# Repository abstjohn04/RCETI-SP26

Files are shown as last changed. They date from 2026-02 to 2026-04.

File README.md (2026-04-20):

# RCETI

Robotic Control of Endotracheal Tube Insertion

## Overview

R.C.E.T.I is a ROS 2 autonomous intubation device. The system utilizes a multi axis rigid linear actuator frame to position the device at the patient's airway, and a 4 tendon continuum robotic tube to safely navigate the throat.

This project assumes the user is controlling the robot remotely via a Raspberry Pi and is using Ubuntu 22.04 LTS.

### Github Branches

**RCETI is currently divided into two branches.**  

The "main" branch contains the most recent stable code that has been tested on the physical robot. It contains updated and more precise servo movements. It does not contain the machine learning algorithms or the updated simulation environment.  

The "development" branch contains the latest code. It has not been tested on the physical robot. It contains the machine learning node and a more polished simulation environment and math engine.

### Requirements

* Ubuntu 22.04
* ROS 2
* Raspberry Pi

### File Structure

#### The workspace is divided into specific ROS 2 packages handling different levels of the robotic stack

**rceti_support**: Contains the URDF, Xarco, and 3D STIL meshes defining the rigid physical frame of the robot.

**rceti_continuum**: The core mathematical engine. It calculates the inverse kinematics (tendon lengths).

**rceti_controller**: The hardware interface running on the Raspberry Pi.

**rceti_keyboard**: A node allowing for manual control of the four independend continuum tendons via keyboard inputs

**rceti_deployment**: The launch files that tie the simulation, hardware, and math nodes together. Contains robot parameters in config/robot_params.yaml

**rceti_vision**: The input node for the machine learning algorithms.

## Installation

See [INSTALL.md](docs/INSTALL.md) to install ROS 2 and setup the environment on the Ubuntu host machine.

## Network Setup

See [NETWORK.md](docs/NETWORK.md) to access the Raspberry Pi.

## Usage

Before launching any ROS node, the user must first source the environment and build.

`colcon build --cmake-args -DCMAKE_EXPORT_COMPILE_COMMANDS=ON`

`source install/setup.bash`

Afterwards, the full network can be launched.

### Commands

`colcon build --packages-select package_name` - Builds a specific node

`ros2 launch rceti_deployment rceti_deployment.launch.xml` - Runs the whole robot system with machine learning disabled. Manual keyboard controls enabled.

`ros2 launch rceti_deployment rceti_deployment.launch.xml use_ai:=true` - Runs the whole robot system with machine learning enabled. Launches mock camera and vision bridge. Manual keyboard controls disabled. UNAVAILABLE IF USING MAIN BRANCH.

`ros2 launch package_name package_launch_file` - Launches a package's launch file (see names of launch files in codebase).

`ros2 run package_name package_run_file` - Runs a specific eligible file in a node (see names of files in codebase).

### RViz simulation tool

This tool launches with the rceti_continuum node. It fetches the modeled meshes from rceti_support and simulates them according to the urdf files (See invididual nodes' .urdf and .xacro files for more details on what is launched and created).  

To disable the Transform frames (all the green, red and blue lines) in the simulation, uncheck the "TF" button in the left settings screen.

### Moving the robot

If you are using the machine learning node with the mock camera, it will automatically move for you!  

To manually move the robot, the rceti_keyboard node must be launched. This will launch a separate terminal which outputs coordinates.  

To adjust the position of the servo mount, use A and D to move left and right, and W and S to move up and down.  
Use L and P to adjust the angle of the servo mount.

To move the tube, use the left and right arrow keys to adjust the Y coordinate (pitch) and the up and down arrow keys to adjust the X coordinate (yaw).

## License & Acknowledgements

This project is licensed under the Apache License 2.0.

Original Work: This repository is a derivative work based on the original [RCETI robotics project](https://github.com/bturner86239/RCETI/graphs/contributors). For a list of original authors, please visit the contributors page of the original repository at `https://github.com/bturner86239/RCETI/graphs/contributors`.

Modifications: In 2026, CSE 2.3 modified the source code, hardware architecture, and simulation environment to implement an independent 4-servo perpendicular continuum drive.

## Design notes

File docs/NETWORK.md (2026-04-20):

# RCETI Network Setup

## Setting Up Static IP on Ubuntu Host

1. Open Settings > Network.
2. Click on Wired Connection (the Ethernet interface).
3. Click Settings (⚙️).
4. Go to the IPv4 tab.
5. Select Manual and set:

    * Address: 192.168.2.1
    * Netmask: 255.255.255.0
    * Gateway: Leave blank

6. Click Apply and disconnect/reconnect Ethernet.

## Setting Up ROS to use static IP

Run these commands in your Ubuntu 22.04 terminal to bind ROS 2 traffic to the Ethernet interface. This will allow communication with the Raspberry Pi.

`echo "export ROS_DOMAIN_ID=7" >> ~/.bashrc ` \
`echo "export ROS_IP=$(hostname -I | awk '{print $1}')" >> ~/.bashrc` \
`echo "export ROS_HOSTNAME=$(hostname -I | awk '{print $1}')" >> ~/.bashrc` \
`source ~/.bashrc` \

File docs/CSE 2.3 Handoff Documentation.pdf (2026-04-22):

# Overview

## https://github.com/abstjohn04/RCETI-SP26

This handoff packet details what team CSE 2.3 completed, the next steps that should be taken, and how to install and use the system.

# What was completed

## Implemented 4 servo design

CSE 2.3 successfully updated the system to support the new 4 servo design. Specifically, it added new variables to the math engine to allow for full movement in the x direction (yaw) and y direction (pitch), added the new 4 servo mount to the simulation’s meshes, and updated the hardware controller to access the new servos.

## Enhanced servo movement

After adding support for the new servos, CSE 2.3 refined their operation. The math calculations were refined to have a smaller step size (allowing for more precise movements). Boundaries were added to the movements in the controller and simulation. Additionally, the code was simplified to allow for simpler modification of servo mappings.

Current math equations used in simulation:

The total bend angle (absolute angle between bottom base and tip):

θ = motor1

2
+ motor3

2

The bending plane angle (direction of the bend)
ϕ = arctan(motor1 / motor3)

The Curvature (tightness of curve dependent on length of the segment) κ = θ / L

## Created Machine Learning ROS Node

The machine learning algorithm was successfully integrated with the rest of the ROS ecosystem by creating a new ROS package (node) specifically to communicate with the separate machine learning codebase. This node uses a mock camera system to play the intubation video from the ML codebase. It contains the “best” (best.py) algorithm which analyzes the camera feed and broadcast movement commands to the math engine and then to the simulation and controller.

## Cleaned up existing codebase

CSE 2.3 removed old files left from previous teams, removed duplicated codefiles, and added detailed documentation to new code in the form of Doxygen comments.

# Future Work Recommendations

## Increased testing with physical robot

CSE 2.3 was not able to thoroughly test the controller node with the physical robot due to hardware wiring issues. While simulation testing proved successful, future teams must retest all of CSE 2.3’s new features on the physical hardware to ensure validity.

Additionally, the current machine learning node uses a mock camera. It is not integrated with the physical camera. To allow the machine learning algorithm to work as intended, any hardware issues with the robot must be corrected and then the camera feed must be fed into the ROS machine learning node. A mock mouth and throat must also be used to allow the machine learning algorithms to work.

## Refine mathematics and bending step size

The current mathematics for the simulation, controller and machine learning must be updated to reflect the dimensions of the actual endotracheal tube to be used. The number of segments and disks and their sizes must be updated in the robot_params.yaml file to allow for accurate calculations. Other mathematical formulas, such as inverse kinematics, should be explored.

## Integrate manual override of machine learning node

Currently, the keyboard node and the ML node cannot be launched simultaneously, due to a joint publishing conflict. To allow for the ability to stop the ML node and give control back to the keyboard, this conflict must be resolved.

## Unified GUI

The current implementation relies on entering terminal commands and interacting through separate gnome terminals. This is unappealing and disconnected. A GUI should be created to allow for easy navigation of the robot, allow for manual keyboard override, and display detailed information about the status of the robot, camera, and ROS system.

# README.md

## https://github.com/abstjohn04/RCETI-SP26/blob/main/README.md

RCETI
Robotic Control of Endotracheal Tube Insertion

Overview
R.C.E.T.I is a ROS 2 autonomous intubation device. The system utilizes a multi axis rigid linear actuator frame to position the device at the patient's airway, and a 4 tendon continuum robotic tube to safely navigate the throat.

This project assumes the user is controlling the robot remotely via a Raspberry Pi and is using Ubuntu 22.04 LTS.

Github Branches
RCETI is currently divided into two branches.

The "main" branch contains the most recent stable code that has been tested on the physical robot. It contains updated and more precise servo movements. It does not contain the machine learning algorithms or the updated simulation environment.

The "development" branch contains the latest code. It has not been tested on the physical robot. It contains the machine learning node and a more polished simulation environment and math engine.

Requirements
Ubuntu 22.04
ROS 2
Raspberry Pi
File Structure
The workspace is divided into specific ROS 2 packages handling different levels of the robotic stack
rceti_support: Contains the URDF, Xarco, and 3D STIL meshes defining the rigid physical frame of the robot.

rceti_continuum: The core mathematical engine. It calculates the inverse kinematics (tendon lengths).

rceti_controller: The hardware interface running on the Raspberry Pi.

rceti_keyboard: A node allowing for manual control of the four independent continuum tendons via keyboard inputs rceti_deployment: The launch files that tie the simulation, hardware, and math nodes together. Contains robot parameters in config/robot_params.yaml

rceti_vision: The input node for the machine learning algorithms.

Installation
See INSTALL.md to install ROS 2 and setup the environment on the Ubuntu host machine.

Network Setup
See NETWORK.md to access the Raspberry Pi.

Usage
Before launching any ROS node, the user must first source the environment and build.

colcon build --cmake-args -DCMAKE_EXPORT_COMPILE_COMMANDS=ON

source install/setup.bash

Afterwards, the full network can be launched.

Commands
colcon build --packages-select package_name - Builds a specific node

ros2 launch rceti_deployment rceti_deployment.launch.xml - Runs the whole robot system with machine learning disabled. Manual keyboard controls enabled.

ros2 launch rceti_deployment rceti_deployment.launch.xml use_ai:=true - Runs the whole robot system with machine learning enabled. Launches mock camera and vision bridge. Manual keyboard controls disabled. UNAVAILABLE IF USING MAIN BRANCH.

ros2 launch package_name package_launch_file - Launches a package's launch file (see names of launch files in codebase).

ros2 run package_name package_run_file - Runs a specific eligible file in a node (see names of files in codebase).

RViz simulation tool
This tool launches with the rceti_continuum node. It fetches the modeled meshes from rceti_support and simulates them according to the urdf files (See invididual nodes' .urdf and .xacro files for more details on what is launched and created).

To disable the Transform frames (all the green, red and blue lines) in the simulation, uncheck the "TF" button in the left settings screen.

Moving the robot
If you are using the machine learning node with the mock camera, it will automatically move for you!

To manually move the robot, the rceti_keyboard node must be launched. This will launch a separate terminal which outputs coordinates.

To adjust the position of the servo mount, use A and D to move left and right, and W and S to move up and down.
Use L and P to adjust the angle of the servo mount.

To move the tube, use the left and right arrow keys to adjust the Y coordinate (pitch) and the up and down arrow keys to adjust the X coordinate (yaw).

License & Acknowledgements
This project is licensed under the Apache License 2.0.

Original Work: This repository is a derivative work based on the original RCETI robotics project. For a list of original authors, please visit the contributors page of the original repository at https://github.com/bturner86239/RCETI/graphs/contributors.

Modifications: In 2026, CSE 2.3 modified the source code, hardware architecture, and simulation environment to implement an independent 4-servo perpendicular continuum drive.

# INSTALL.md

https://github.com/abstjohn04/RCETI-SP26/blob/main/docs/INSTALL.

## md (https://github.com/abstjohn04/RCETI-SP26/blob/main/docs/INSTALL.md)

RCETI System Setup & Installation
Setup Ubuntu Host System
First, we need to ensure the Ubuntu host machine is up to date and has the basic tools required to download the robotics software.

Open a new Terminal window (Ctrl + Alt + T).
Enter the following command and press enter:
sudo apt update && sudo apt upgrade -y
(Note: If prompted with "A new version of Ubuntu is available. Would you like to upgrade?", select "Do Not Upgrade". The robot specifically requires Ubuntu 22.04)
Restart the Ubuntu host machine
Install ROS 2
RCETI runs on ROS 2 Humble. Run the following commands one by one in your terminal to install the core robotic libraies.

Add the ROS 2 Repository
sudo apt install software-properties-common
sudo add-apt-repository universe
sudo apt update && sudo apt install curl -y
export ROS_APT_SOURCE_VERSION=$(curl -s
https://api.github.com/repos/ros-infrastructure/ros-apt-source/releases/latest | grep -F
"tag_name" | awk -F\" '{print $4}')
Install the Core Software
curl -L -o /tmp/ros2-apt-source.deb "https://github.com/ros-infrastructure/ros-apt-source/releases/download/${ROS_APT_SOURCE_VERSION}/ros2-apt-source_${ROS_APT_SOURCE_VERSION}.$(. /etc/os-release && echo ${UBUNTU_CODENAME:-${VERSION_CODENAME}})_all.deb"
sudo dpkg -i /tmp/ros2-apt-source.deb
sudo apt update && sudo apt install ros-humble-desktop -y && sudo apt install ros-humble-moveit -y && sudo apt install python3-colcon-common-extensions -y && sudo apt install python3-rosdep2 -y
Restart the Ubuntu host machine.
Set up the ROS environment
Next we will setup the ROS environment. Enter the following commands in your terminal one by one.

Source the setup files:
source /opt/ros/humble/setup.bash

If sourcing the files works, make it run automatically
echo "source /opt/ros/humble/setup.bash" >> ~/.bashrc
Close the current terminal and open a new one (Ctrl + Alt + T)
Create a new folder named “rceti_ws” with a subfolder named “src” in your home directory to store the code:
cd && mkdir -p rceti_ws/src
Download & Build the RCETI Code
Now that the robotics software is installed, we will download the RCETI code and the Machine Learning code. Once again, follow the steps and enter the commands in your terminal.

Install git:
sudo apt update && sudo apt install git -y
Clone the RCETI repo to rceti/src (make sure to include the dot at the end of the command!): cd ~/rceti/src && git clone https://github.com/abstjohn04/RCETI-SP26 .
Clone the Machine Learning repo to a new folder called ML (or any folder you wish): cd && mkdir ML && && cd ML && git clone https://github.com/github4bme/EndotrachealTubeModel . (Note: The machine learning repo is massive. It may take up to a hour to fully download.)
If you wish to use the mock machine learning camera, you must change the file path for "video_path" in rceti/src/rceti_vision/rceti_vision/mock_camera.py to match the location of your cloned machine learning repo.
Enter the rceti_ws/ directory and install dependencies:
cd ~/rceti_ws
rosdep update
rosdep install -i --from-path src --rosdistro humble -y colcon build
Restart the Ubuntu host machine (CRUCIAL!)
Validating the installation
To test the RCETI robot, enter the following command:
cd ~/rceti_ws/ && source install/setup.bash && ros2 launch rceti_deployment rceti_deployment.launch.xml

If the installation and launch was successful, three things will open on your screen:

The 3D Simulation (RViz): The 3D live model of the robot.
The Data Terminal: A window displaying the real time math calculations and the coordinates. The System Log: The original terminal where you typed the command will begin streaming the system health status.
To close the application, navigate to the System Log terminal window and press "Ctrcl + C". Close the other windows manually if needed.

See NETWORK.md for instructions on how to access the Raspberry Pi.

See the "Usage" section in README.md on how to use the system.

# NETWORK.md

## https://github.com/abstjohn04/RCETI-SP26/blob/main/docs/NETWOR K.md (https://github.com/abstjohn04/RCETI-SP26/blob/main/docs/NETWORK.md)

RCETI Network Setup
Setting Up Static IP on Ubuntu Host
Open Settings > Network.

Click on Wired Connection (the Ethernet interface).

Click Settings (⚙️).

Go to the IPv4 tab.

Select Manual and set:

Address: 192.168.2.1
Netmask: 255.255.255.0
Gateway: Leave blank
Click Apply and disconnect/reconnect Ethernet.

Setting Up ROS to use static IP
Run these commands in your Ubuntu 22.04 terminal to bind ROS 2 traffic to the Ethernet interface. This will allow communication with the Raspberry Pi.

echo "export ROS_DOMAIN_ID=7" >> ~/.bashrc
echo "export ROS_IP=$(hostname -I | awk '{print $1}')" >> ~/.bashrc
echo "export ROS_HOSTNAME=$(hostname -I | awk '{print $1}')" >> ~/.bashrc
source ~/.bashrc \

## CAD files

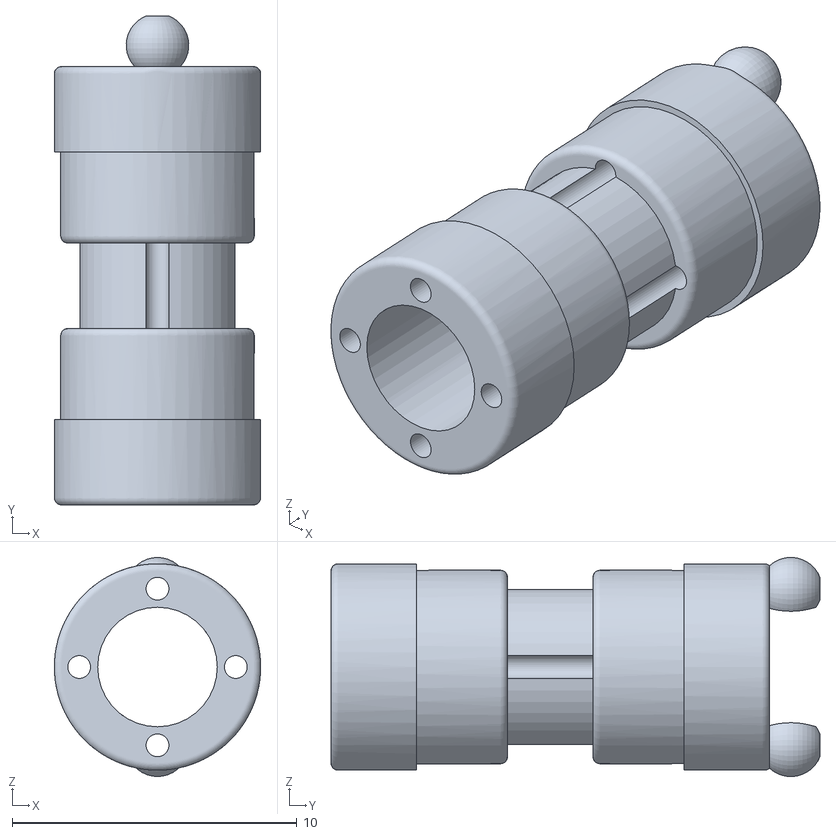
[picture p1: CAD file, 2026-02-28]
rceti_support/meshes/visual/scaled_down_by_1000/IF_camera_frame_V3.0_4.2mm_original.STL
7.25 x 17.2 x 7.70

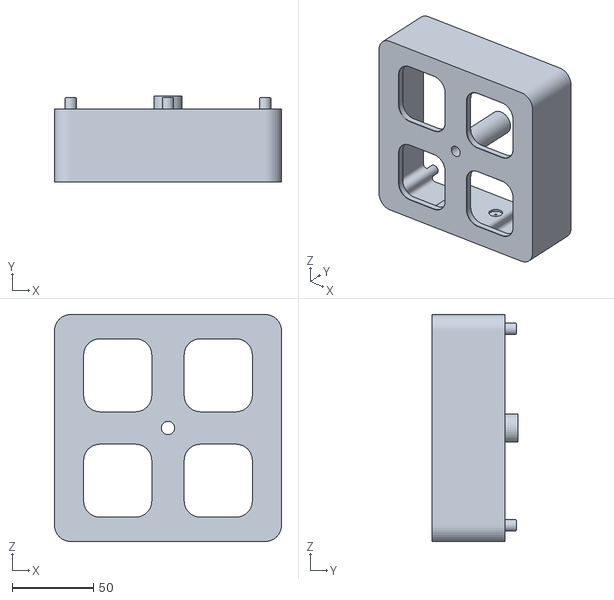
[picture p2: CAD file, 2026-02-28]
rceti_support/meshes/visual/scaled_down_by_1000/IF_Attachment_V9_Piece_bottom.STL
140.0 x 52.8 x 140.0

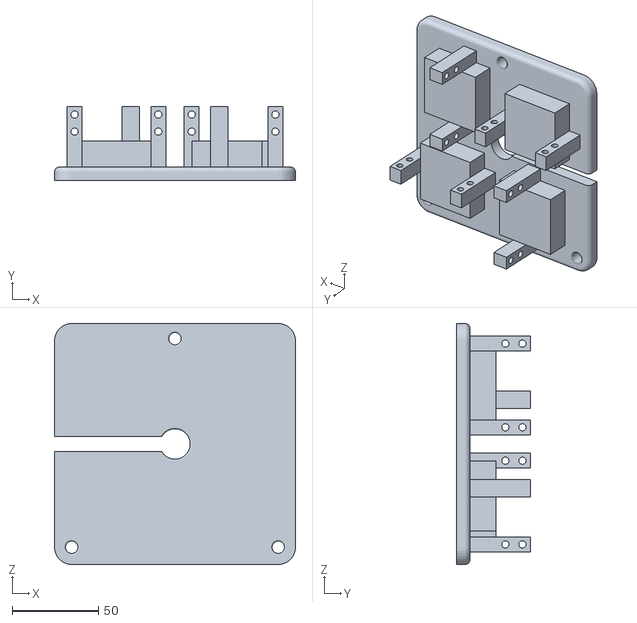
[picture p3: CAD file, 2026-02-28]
rceti_support/meshes/visual/scaled_down_by_1000/IF_Attachment_Piece_V1.4_Top.STL
140.0 x 42.8 x 140.0

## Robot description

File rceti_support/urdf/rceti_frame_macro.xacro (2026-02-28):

<?xml version="1.0" ?>
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
<robot xmlns:xacro="http://ros.org/wiki/xacro" name="rceti_robot">
    
    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
    
    <xacro:property name="meshes_directory" default=""/>

    <xacro:macro name="rceti_robot" params="meshes_directory">
        
        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
        <link name="base_link">
            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
        </link>

        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
        <link name="x_actuator_link">
            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
        </link>

        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
        <link name="x_slider_link">
            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
        </link>

        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
        <link name="z_actuator_link">
            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
        </link>

        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
        <link name="z_slider_link">
            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
            
        </link>

        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
        <link name="pitch_servo_link">
            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
        </link>

        <link name="pitch_servo_bottom_link">
            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
        </link>

        <link name="continuum_base_link">
            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
        </link>

        <link name="continuum_base_link_top">
            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
        </link>

        <link name="continuum_base_link_bottom">
            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
        </link>

        <link name="continuum_base_link_left">
            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
        </link>

        <link name="continuum_base_link_right">
            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
        </link>

        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
        <joint name="base_to_x_actuator" type="fixed">
            <parent link="base_link"/>
            <child link="x_actuator_link"/>
            <origin xyz="0 0 0.35"/>  
        </joint>

        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
        <joint name="x_actuator_to_x_slider" type="prismatic">
            <parent link="x_actuator_link"/>
            <child link="x_slider_link"/>
            <origin xyz="0.0580 0.027 0.014"/>
            <axis xyz="1 0 0"/>  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
            <limit effort="100.0" lower="0" upper="0.308" velocity="0.5"/>
        </joint>

        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
        <joint name="x_slider_to_z_actuator" type="fixed">
            <parent link="x_slider_link"/>
            <child link="z_actuator_link"/>
            <origin xyz="0 0.03965 0.13176"/>
        </joint>

        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
        <joint name="z_actuator_to_z_slider" type="prismatic">
            <parent link="z_actuator_link"/>
            <child link="z_slider_link"/>
            <origin xyz="0 0.026 -0.0580"/>
            <axis xyz="0 0 -1"/>
            <limit effort="100.0" lower="0.0" upper="0.309" velocity="0.5"/>
        </joint>

        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
        <joint name="z_slider_to_pitch_servo" type="revolute">
            <parent link="z_slider_link"/>
            <child link="pitch_servo_link"/>
            <origin xyz="0 0.02 0" rpy="${pi/2} 0 ${pi}"/>
            <axis xyz="0 0 1"/>
            <limit effort="50.0" lower="0.730" upper="-0.475" velocity="1.0"/>
        </joint>

        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
        <joint name="pitch_bottom_to_top" type="fixed">
            <parent link="pitch_servo_link"/>
            <child link="pitch_servo_bottom_link"/>
            <origin xyz="0 0.017 0"/>
        </joint>

        <joint name="continuum_top" type="revolute">
            <parent link="pitch_servo_bottom_link"/>
            <child link="continuum_base_link_top"/>
            <origin xyz="0 0.017 0"/>
            <axis xyz="0 0 1"/> 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
            <limit effort="50.0" lower="-0.5" upper="0.5" velocity="1.0"/> 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
        </joint>

        <joint name="continuum_bottom" type="revolute">
            <parent link="pitch_servo_bottom_link"/>
            <child link="continuum_base_link_bottom"/>
            <origin xyz="0 0.017 0"/>
            <axis xyz="0 0 1"/> 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
            <limit effort="50.0" lower="-0.5" upper="0.5" velocity="1.0"/> 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
        </joint>

        <joint name="continuum_left" type="revolute">
            <parent link="pitch_servo_bottom_link"/>
            <child link="continuum_base_link_left"/>
            <origin xyz="0 0.017 0"/>
            <axis xyz="0 0 1"/> 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
            <limit effort="50.0" lower="-0.5" upper="0.5" velocity="1.0"/> 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
        </joint>

        <joint name="continuum_right" type="revolute">
            <parent link="pitch_servo_bottom_link"/>
            <child link="continuum_base_link_right"/>
            <origin xyz="0 0.017 0"/>
            <axis xyz="0 0 1"/> 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
            <limit effort="50.0" lower="-0.5" upper="0.5" velocity="1.0"/> 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
        </joint>

    </xacro:macro>
    <xacro:rceti_robot meshes_directory="$(arg meshes_directory)"/>
</robot>

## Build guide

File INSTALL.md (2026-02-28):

# RCETI System Setup & Installation

## Setup Ubuntu Host System

First, we need to ensure the Ubuntu host machine is up to date and has the basic tools required to download the robotics software.

1. Open a new Terminal window (Ctrl + Alt + T).
2. Enter the following command and press enter:  
`sudo apt update && sudo apt upgrade -y`  
*(Note: If prompted with "A new version of Ubuntu is available. Would you like to upgrade?", select **"Do Not Upgrade"**. The robot specifically requires Ubuntu 22.04)*
3. Restart the Ubuntu host machine

## Install ROS 2

RCETI runs on ROS 2 Humble. Run the following commands one by one in your terminal to install the core robotic libraies.

1. Add the ROS 2 Repository
    * `sudo apt install software-properties-common`
    * `sudo add-apt-repository universe`
    * `sudo apt update && sudo apt install curl -y`
    * `export ROS_APT_SOURCE_VERSION=$(curl -s https://api.github.com/repos/ros-infrastructure/ros-apt-source/releases/latest | grep -F "tag_name" | awk -F\" '{print $4}')`
2. Install the Core Software
    * `curl -L -o /tmp/ros2-apt-source.deb "https://github.com/ros-infrastructure/ros-apt-source/releases/download/${ROS_APT_SOURCE_VERSION}/ros2-apt-source_${ROS_APT_SOURCE_VERSION}.$(. /etc/os-release && echo ${UBUNTU_CODENAME:-${VERSION_CODENAME}})_all.deb"`
    * `sudo dpkg -i /tmp/ros2-apt-source.deb`
    * `sudo apt update && sudo apt install ros-humble-desktop -y && sudo apt install ros-humble-moveit -y && sudo apt install python3-colcon-common-extensions -y && sudo apt install python3-rosdep2 -y`
3. Restart the Ubuntu host machine.

## Set up the ROS environment

Next we will setup the ROS environment. Enter the following commands in your terminal one by one.

1. Source the setup files:  
    `source /opt/ros/humble/setup.bash`
2. If sourcing the files works, make it run automatically  
    `echo "source /opt/ros/humble/setup.bash" >> ~/.bashrc`
3. Close the current terminal and open a new one (Ctrl + Alt + T)
4. Create a new folder named “rceti_ws” with a subfolder named “src” in your home directory to store the code:  
    ``cd && mkdir -p rceti_ws/src``

## Download & Build the RCETI Code

Now that the robotics software is installed, we will download the RCETI specific code. Once again, follow the steps and enter the commands in your terminal.

1. Install git:  
    `sudo apt update && sudo apt install git -y`
2. Clone the repo to rceti/src (make sure to include the dot at the end of the command!):  
    `cd ~/rceti/src && git clone https://github.com/abstjohn04/RCETI-SP26 .`
3. Enter the rceti_ws/ directory and install dependencies:  
    * `cd ~/rceti_ws`
    * `rosdep update`
    * `rosdep install -i --from-path src --rosdistro humble -y`
    * `colcon build`
4. Restart the Ubuntu host machine (CRUCIAL!)

## Running the Robot System

To Start the RCETI robot, enter the following command:  
    `cd ~/rceti_ws/ && source install/setup.bash && ros2 launch rceti_deployment rceti_deployment.launch.xml`

If the installation and launch was successful, four things will open on your screen:

1. **The 3D Simulation (RViz)**: The 3D live model of the robot.
2. **The Control Terminal**: A new terminal will pop up allowing you to use your WASD and Arrow keys to control the physical robot
3. **The Data Terminal**: A window displaying the real time math calculations and the coordinates.
4. **The System Log**: The original terminal where you typed the command will begin streaming the system health status.

To close the application, navigate to the System Log terminal window and press "Ctrcl + C". Close the other windows manually if needed

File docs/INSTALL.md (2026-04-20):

# RCETI System Setup & Installation

## Setup Ubuntu Host System

First, we need to ensure the Ubuntu host machine is up to date and has the basic tools required to download the robotics software.

1. Open a new Terminal window (Ctrl + Alt + T).
2. Enter the following command and press enter:  
`sudo apt update && sudo apt upgrade -y`  
*(Note: If prompted with "A new version of Ubuntu is available. Would you like to upgrade?", select **"Do Not Upgrade"**. The robot specifically requires Ubuntu 22.04)*
3. Restart the Ubuntu host machine

## Install ROS 2

RCETI runs on ROS 2 Humble. Run the following commands one by one in your terminal to install the core robotic libraies.

1. Add the ROS 2 Repository
    * `sudo apt install software-properties-common`
    * `sudo add-apt-repository universe`
    * `sudo apt update && sudo apt install curl -y`
    * `export ROS_APT_SOURCE_VERSION=$(curl -s https://api.github.com/repos/ros-infrastructure/ros-apt-source/releases/latest | grep -F "tag_name" | awk -F\" '{print $4}')`
2. Install the Core Software
    * `curl -L -o /tmp/ros2-apt-source.deb "https://github.com/ros-infrastructure/ros-apt-source/releases/download/${ROS_APT_SOURCE_VERSION}/ros2-apt-source_${ROS_APT_SOURCE_VERSION}.$(. /etc/os-release && echo ${UBUNTU_CODENAME:-${VERSION_CODENAME}})_all.deb"`
    * `sudo dpkg -i /tmp/ros2-apt-source.deb`
    * `sudo apt update && sudo apt install ros-humble-desktop -y && sudo apt install ros-humble-moveit -y && sudo apt install python3-colcon-common-extensions -y && sudo apt install python3-rosdep2 -y`
3. Restart the Ubuntu host machine.

## Set up the ROS environment

Next we will setup the ROS environment. Enter the following commands in your terminal one by one.

1. Source the setup files:  
    `source /opt/ros/humble/setup.bash`
2. If sourcing the files works, make it run automatically  
    `echo "source /opt/ros/humble/setup.bash" >> ~/.bashrc`
3. Close the current terminal and open a new one (Ctrl + Alt + T)
4. Create a new folder named “rceti_ws” with a subfolder named “src” in your home directory to store the code:  
    ``cd && mkdir -p rceti_ws/src``

## Download & Build the RCETI Code

Now that the robotics software is installed, we will download the RCETI code and the Machine Learning code. Once again, follow the steps and enter the commands in your terminal.

1. Install git:  
    `sudo apt update && sudo apt install git -y`
2. Clone the RCETI repo to rceti/src (make sure to include the dot at the end of the command!):  
    `cd ~/rceti/src && git clone https://github.com/abstjohn04/RCETI-SP26 .`
3. Clone the Machine Learning repo to a new folder called ML (or any folder you wish):
    `cd && mkdir ML && && cd ML && git clone https://github.com/github4bme/EndotrachealTubeModel .`
    *(Note: The machine learning repo is massive. It may take up to a hour to fully download.)*
4. If you wish to use the mock machine learning camera, you must change the file path for "video_path" in rceti/src/rceti_vision/rceti_vision/mock_camera.py to match the location of your cloned machine learning repo.
5. Enter the rceti_ws/ directory and install dependencies:  
    * `cd ~/rceti_ws`
    * `rosdep update`
    * `rosdep install -i --from-path src --rosdistro humble -y`
    * `colcon build`
6. Restart the Ubuntu host machine (CRUCIAL!)

## Validating the installation

To test the RCETI robot, enter the following command:  
    `cd ~/rceti_ws/ && source install/setup.bash && ros2 launch rceti_deployment rceti_deployment.launch.xml`

If the installation and launch was successful, three things will open on your screen:

1. **The 3D Simulation (RViz)**: The 3D live model of the robot.
2. **The Data Terminal**: A window displaying the real time math calculations and the coordinates.
3. **The System Log**: The original terminal where you typed the command will begin streaming the system health status.

To close the application, navigate to the System Log terminal window and press "Ctrcl + C". Close the other windows manually if needed.  

See [NETWORK.md](NETWORK.md) for instructions on how to access the Raspberry Pi.  

See the "Usage" section in [README.md](../README.md) on how to use the system.

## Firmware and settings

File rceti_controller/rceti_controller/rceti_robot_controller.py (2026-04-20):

# MODIFICATION NOTICE
# This file is part of a derivative work based on the original RCETI project (https://github.com/bturner86239/RCETI).
# It was modified by CSE 2.3 in March, 2026 in accordance with Section 4(b) of the Apache License 2.0.

# Major Changes:
# Added support for two new continuum_motors.
import math
import rclpy
from rclpy.node import Node
from sensor_msgs.msg import JointState
import time  # for delays/testing

# A try catch block to detect the raspberry pi. Enters mock mode for simulation testing if it is not detected.
try:
    import lgpio
    from adafruit_servokit import ServoKit
    import adafruit_motor.servo
    HARDWARE_MODE = True
    kit = ServoKit(channels=16)
    print("Raspberry Pi Hardware detected. Running in HARDWARE mode.")

except (ImportError, NotImplementedError):
    print("WARNING: Raspberry Pi Hardware not detected. Running in MOCK SIMULATION mode.")
    HARDWARE_MODE = False

    class MockServo:
        """A mock representation of an Adafruit servo motor for simulation testing."""
        
        def __init__(self):
            """Initializes the mock servo with a default actuation range."""
            self._angle = None
            self.actuation_range = 180
            
        def set_pulse_width_range(self, min_p, max_p):
            """Mocks the hardware method for setting the pulse width range.
            
            Args:
                min_p (int): The minimum pulse width in microseconds.
                max_p (int): The maximum pulse width in microseconds.
            """
            pass

        @property
        def angle(self):
            """Gets the current angle of the simulated servo.
            
            Returns:
                float: The current angle.
            """
            return self._angle
        
        @angle.setter
        def angle(self, val): 
            """Sets the angle of the simulated servo.
            
            Args:
                val (float): The desired angle to set.
            """
            self._angle = val

    class MockServoKit:
        """A mock representation of the Adafruit servo controller."""

        def __init__(self, channels):
            """Initializes the mock servo kit with a specified number of channels.
            
            Args:
                channels (int): The total number of servo channels available on the board.
            """
            self.servo = [MockServo() for _ in range(channels)]

    class MockLgpio:
        """A mock representation of the lgpio library for simulating Raspberry Pi GPIO pins."""

        def gpiochip_open(self, chip): 
            """Mocks opening the GPIO chip for access.
            
            Args:
                chip (int): The GPIO chip number to open.
                
            Returns:
                int: A dummy handle ID for the opened chip.
            """
            return 1
        
        def gpio_claim_output(self, chip, pin): 
            """Mocks claiming a specific GPIO pin for digital output.
            
            Args:
                chip (int): The handle ID of the GPIO chip.
                pin (int): The physical pin number to claim.
            """
            pass

        def gpio_write(self, chip, pin, val):
            """Mocks writing a digital high or low state to a GPIO pin.
            
            Args:
                chip (int): The handle ID of the GPIO chip.
                pin (int): The physical pin number to write to.
                val (int): The value to write (1 for HIGH, 0 for LOW).
            """
            pass

    kit = MockServoKit(channels=16)
    lgpio = MockLgpio()

TOPIC_SUBSCRIPTION_BUFFER = 5

class RCETIRobotController(Node):
    """RCETIRobotController is a ROS 2 node that controls the RCETI robot's stepper motors and pitch servo.

    Args:
        Node (Node): The node of the ROS 2 system that handles the robot's control logic.
    """

    def __init__(self):
        """Initializes the RCETIRobotController node, subscribes to the /joint_states topic, and sets up GPIO pins for stepper motors and servo motors."""
        
        super().__init__('rceti_controller')

        # Initialize servo motors
        self.servo1 = kit.servo[0]       # tilts continuum base
        self.servo2 = kit.servo[4]       # pulls continuum (N)
        self.servo3 = kit.servo[2]       # pulls continuum (S)
        self.servo4 = kit.servo[3]       # pulls continuum (W)
        self.servo5 = kit.servo[1]       # pulls continuum (E)

        self.servo1.actuation_range = 200
        self.servo1.set_pulse_width_range(500, 2000)

        # CONTINUUM SERVO BOUND CONSTANTS
        self.continuum_servo_half_range = 20
        self.continuum_servo_middle = 90

        # May need to adjust 
        self.servo2.actuation_range = 180
        self.servo2.set_pulse_width_range(500, 2500)
        # May need to adjust 
        self.servo3.actuation_range = 180
        self.servo3.set_pulse_width_range(500, 2500)
        # May need to adjust 
        self.servo4.actuation_range = 180
        self.servo4.set_pulse_width_range(500, 2500)
        # May need to adjust 
        self.servo5.actuation_range = 180
        self.servo5.set_pulse_width_range(500, 2500)

        # Subscribe to the /joint_states topic
        self.joint_state_sub = self.create_subscription(
            JointState,
            '/joint_states',
            self.joint_state_callback,
            TOPIC_SUBSCRIPTION_BUFFER
        )

        # Position tracking
        self.x_position = 0.0
        self.z_position = 0.0
        self.pitch_angle = 0.730

        # GPIO pin definitions
        self.X_DIRECTION_PIN = 21
        self.X_PULSE_PIN = 20
        self.Z_DIRECTION_PIN = 19
        self.Z_PULSE_PIN = 18

        # Open the GPIO chip and set the pins as output
        self.chip = lgpio.gpiochip_open(0)
        lgpio.gpio_claim_output(self.chip, self.X_DIRECTION_PIN)
        lgpio.gpio_claim_output(self.chip, self.X_PULSE_PIN)
        lgpio.gpio_claim_output(self.chip, self.Z_DIRECTION_PIN)
        lgpio.gpio_claim_output(self.chip, self.Z_PULSE_PIN)

        # Define stepper steps per unit in X and Z directions
        self.steps_per_mm_x = 40
        self.steps_per_mm_z = 40

    def joint_state_callback(self, msg):
        """Handles incoming joint state messages and moves the stepper motors accordingly.
        This function is called whenever a new message is received on the /joint_states topic.
        Moves the x stepper motor, z stepper motor, and pitch servo motor based on the joint states received.

        Args:
            msg (sensor_msgs/JointState.msg): The messages recieved from the /joint_states topic.
        """
        # Extract joint positions from the message
        try:
            x_index = msg.name.index('x_actuator_to_x_slider')
            z_index = msg.name.index('z_actuator_to_z_slider')
            pitch_index = msg.name.index('z_slider_to_pitch_servo')
            continuum_index_1 = msg.name.index('continuum_motor_1')
            continuum_index_2 = msg.name.index('continuum_motor_2')
            continuum_index_3 = msg.name.index('continuum_motor_3')
            continuum_index_4 = msg.name.index('continuum_motor_4')

            new_x_position = msg.position[x_index]
            new_z_position = msg.position[z_index]
            pitch_angle_msg = msg.position[pitch_index]
            continuum_angle_1 = msg.position[continuum_index_1]
            continuum_angle_2 = msg.position[continuum_index_2]
            continuum_angle_3 = msg.position[continuum_index_3]
            continuum_angle_4 = msg.position[continuum_index_4]

            # Handle X-axis movement
            if self.x_position != new_x_position:
                self.get_logger().info(f"Moving X to {new_x_position}")
                steps = int(abs(new_x_position - self.x_position) * 1000 * self.steps_per_mm_x)
                direction = 1 if new_x_position > self.x_position else 0
                self.move_stepper(steps, direction, self.X_DIRECTION_PIN, self.X_PULSE_PIN)
                self.x_position = new_x_position

            # Handle Z-axis movement
            if self.z_position != new_z_position:
                self.get_logger().info(f"Moving Z to {new_z_position}")
                steps = int(abs(new_z_position - self.z_position) * 1000 * self.steps_per_mm_z)
                direction = 1 if new_z_position > self.z_position else 0
                self.move_stepper(steps, direction, self.Z_DIRECTION_PIN, self.Z_PULSE_PIN)
                self.z_position = new_z_position

            # Handle pitch and continuum angles with safety clamps
            new_pitch_angle = self.clamp_angle(((pitch_angle_msg + 0.475) / 1.205) * 120)
            
            # new_continuum_1_pitch_angle = self.clamp_angle(((continuum_angle_1 + 0.475) / 1.205) * 120)
            # new_continuum_2_pitch_angle = self.clamp_angle(((continuum_angle_2 + 0.475) / 1.205) * 120)
            # new_continuum_3_pitch_angle = self.clamp_angle(((continuum_angle_3 + 0.475) / 1.205) * 120)
            # new_continuum_4_pitch_angle = self.clamp_angle(((continuum_angle_4 + 0.475) / 1.205) * 120)

            servo1_angle = self.clamp_continuum_angle(self.convert_continuum_angle(continuum_angle_1))
            servo2_angle = self.clamp_continuum_angle(self.convert_continuum_angle(continuum_angle_2))
            servo3_angle = self.clamp_continuum_angle(self.convert_continuum_angle(continuum_angle_3))
            servo4_angle = self.clamp_continuum_angle(self.convert_continuum_angle(continuum_angle_4))

            if (self.servo1.angle != new_pitch_angle): 
                self.get_logger().info(f"Adjusting pitch to {new_pitch_angle}")
                self.servo1.angle = new_pitch_angle

            if (self.servo2.angle != servo1_angle): 
                self.get_logger().info(f"Adjusting continuum 1 to {servo1_angle}")
                self.servo2.angle = servo1_angle

            if (self.servo3.angle != servo2_angle): 
                self.get_logger().info(f"Adjusting continuum 2 to {servo2_angle}")
                self.servo3.angle = servo2_angle
                
            if (self.servo4.angle != servo3_angle): 
                self.get_logger().info(f"Adjusting continuum 3 to {servo3_angle}")
                self.servo4.angle = servo3_angle

            if (self.servo5.angle != servo4_angle): 
                self.get_logger().info(f"Adjusting continuum 4 to {servo4_angle}")
                self.servo5.angle = servo4_angle

        except ValueError as e:
            self.get_logger().error(f"Joint name not found in joint_states: {e}")

    def move_stepper(self, steps, direction, direction_pin, pulse_pin, delay=0.001):
        """Stepper Motor Helper Function, handles all stepper movement

        Args:
            steps (int): the amount of "steps" the stepper motor will take
            direction (int/bool): the direction the stepper motor will move, 0 is for backward, 1 is for forward
            direction_pin (int): the GPIO pin used to set the direction of the stepper motor
            pulse_pin (int): the GPIO pin used to pulse the stepper motor
            delay (float, optional): the delay between steps, defaults to 0.001.
        """
        
        if HARDWARE_MODE:
            self.get_logger().info(f"Hardware pulsing: steps={steps}, dir={direction}")
            lgpio.gpio_write(self.chip, direction_pin, direction)

            for _ in range(steps):
                lgpio.gpio_write(self.chip, pulse_pin, 1)
                time.sleep(delay)
                lgpio.gpio_write(self.chip, pulse_pin, 0)
                time.sleep(delay)
        else:
            # Skip time.sleep() so it is reflected in simulation instanly
            self.get_logger().info(f"[MOCK] Simulated moving stepper: steps={steps}, dir={direction}")

    def clamp_angle(self, value):
        """Clamps the calculated angle between 0 and 120 degrees."""
        return max(0, min(120, int(value)))

    def convert_continuum_angle(self, value):
        """
        Converts value from joint state (-0.5, 0.5) to servo angle
        (continuum_servo_middle +- continuum_servo_half_angle).
        """
        return (value * self.continuum_servo_half_range * 2) + 90

    def clamp_continuum_angle(self, value):
        """Clamps the angle between the min and max range set by constants."""
        return max(
            self.continuum_servo_middle - self.continuum_servo_half_range,
            min(
                self.continuum_servo_middle + self.continuum_servo_half_range,
                value
            )
        )

def main(args=None):
    """The main function initializes the ROS 2 node and starts the RCETIRobotController.

    Args:
        args (N/A optional):Defaults to None, shouldn't be set to anything
    """
    rclpy.init(args=args)
    robot_controller = RCETIRobotController()
    rclpy.spin(robot_controller)

    robot_controller.destroy_node()
    rclpy.shutdown()

if __name__ == '__main__':
    main()

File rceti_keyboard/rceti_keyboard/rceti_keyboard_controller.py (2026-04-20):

# MODIFICATION NOTICE
# This file is part of a derivative work based on the original RCETI project (https://github.com/bturner86239/RCETI).
# It was modified by CSE 2.3 in March, 2026 in accordance with Section 4(b) of the Apache License 2.0.

# Major Changes:
# Added two new continuum_motors. Refactored code with swtich case statement and added helper method _update_joint
import sys
import termios
import tty
import time
from select import select
from sensor_msgs.msg import JointState
import rclpy
from rclpy.node import Node

LINEAR_STEP = 0.01
FIVE_DEGREES_FUNCTIONAL = 0.050208333
class Press:
    UP_ARROW = '\x1b[A'
    DOWN_ARROW = '\x1b[B'
    RIGHT_ARROW = '\x1b[C'
    LEFT_ARROW = '\x1b[D'
    CTRL_C = '\x03'
    ESC = '\x1b'
class RcetiKeyboardController(Node):
    """RcetiKeyboardController is a ROS 2 node that handles keyboard input to control the RCETI robot's joint states.

    Args:
        Node (Node): The node of the ROS 2 system that handles the keyboard input and joint state publishing.
    """

    def __init__(self):
        """Initializes the RcetiKeyboardController node, sets up the publisher for joint states, and initializes parameters.
        """
        super().__init__('rceti_keyboard')
        self.joint_state_publisher = self.create_publisher(JointState, '/joint_states', 10)

        self.MIN_X_POSITION, self.MAX_X_POSITION = 0.0, 0.309
        self.MIN_Z_POSITION, self.MAX_Z_POSITION = 0.0, 0.309
        self.MIN_PITCH_ANGLE, self.MAX_PITCH_ANGLE  = -0.475, 0.730
        self.MIN_CONTINUUM_ANGLE, self.MAX_CONTINUUM_ANGLE = -0.5, 0.5
        
        self.x_position = self.MIN_X_POSITION
        self.z_position = self.MIN_Z_POSITION
        self.pitch_angle =  self.MAX_PITCH_ANGLE
        
        # UPDATED TO SET SERVOS TO PROPER ANGLE BASED ON NEW 4-SERVO CONFIGURATION
        self.continuum_motor_1_angle = 0.0
        self.continuum_motor_2_angle = 0.0
        self.continuum_motor_3_angle = 0.0
        self.continuum_motor_4_angle = 0.0

        self.original_settings = termios.tcgetattr(sys.stdin)

        self.declare_parameter('key_timeout', 0.1)

        self.keyboard_timer = self.create_timer(0.01, self.keyboard_callback)
        self.joint_state_timer = self.create_timer(0.1, self.publish_joint_states)
        
    def _detectKey(self, timeout):
        """Detects a key press from the keyboard with a timeout.

        Args:
            timeout (float): The timeout duration in seconds.

        Returns:
            string: The key pressed or an empty string if no key was pressed within the timeout.
        """
        tty.setraw(sys.stdin.fileno())
        rlist, _, _ = select([sys.stdin], [], [], timeout)

        if rlist:
            keysPressed = sys.stdin.read(1)  # Read the first character
            if keysPressed == Press.ESC:  # Escape character
                keysPressed += sys.stdin.read(2)  # Read the '[' and the final character (e.g., 'A', 'B', 'C', or 'D')
            termios.tcsetattr(sys.stdin, termios.TCSADRAIN, self.original_settings)
            time.sleep(0.05)
            return keysPressed
        
        termios.tcsetattr(sys.stdin, termios.TCSADRAIN, self.original_settings)
        return ''

    def _update_joint(self, new_val, min_val, max_val, name):
        """Helper method to cleanly update a joint value and enforce hardware boundaries.
        """
        if new_val > max_val:
            self.get_logger().info(f"Cannot increase {name}, at maximum limit.")
            return max_val
        elif new_val < min_val:
            self.get_logger().info(f"Cannot decrease {name}, at minimum limit.")
            return min_val
        return new_val
    
    def keyboard_callback(self):
        """Handles keyboard input to control the robot's joint states."""
        
        keyPressed = self._detectKey(self.get_parameter("key_timeout").get_parameter_value().double_value)

        if not keyPressed: return
        
        match keyPressed:
            case 'd': self.x_position = self._update_joint(self.x_position - LINEAR_STEP, self.MIN_X_POSITION, self.MAX_X_POSITION, "X Position")
            case 'a': self.x_position = self._update_joint(self.x_position + LINEAR_STEP, self.MIN_X_POSITION, self.MAX_X_POSITION, "X Position")
            case 'w': self.z_position = self._update_joint(self.z_position - LINEAR_STEP, self.MIN_Z_POSITION, self.MAX_Z_POSITION, "Z Position")
            case 's': self.z_position = self._update_joint(self.z_position + LINEAR_STEP, self.MIN_Z_POSITION, self.MAX_Z_POSITION, "Z Position")

            case 'p': self.pitch_angle = self._update_joint(self.pitch_angle - FIVE_DEGREES_FUNCTIONAL, self.MIN_PITCH_ANGLE, self.MAX_PITCH_ANGLE, "Pitch Angle")
            case 'l': self.pitch_angle = self._update_joint(self.pitch_angle + FIVE_DEGREES_FUNCTIONAL, self.MIN_PITCH_ANGLE, self.MAX_PITCH_ANGLE, "Pitch Angle")
            
            case Press.UP_ARROW: 
                self.continuum_motor_1_angle = self._update_joint(self.continuum_motor_1_angle + FIVE_DEGREES_FUNCTIONAL, self.MIN_CONTINUUM_ANGLE, self.MAX_CONTINUUM_ANGLE, "Continuum 1")
                self.continuum_motor_2_angle = self._update_joint(self.continuum_motor_2_angle - FIVE_DEGREES_FUNCTIONAL, self.MIN_CONTINUUM_ANGLE, self.MAX_CONTINUUM_ANGLE, "Continuum 2")
            case Press.DOWN_ARROW: 
                self.continuum_motor_1_angle = self._update_joint(self.continuum_motor_1_angle - FIVE_DEGREES_FUNCTIONAL, self.MIN_CONTINUUM_ANGLE, self.MAX_CONTINUUM_ANGLE, "Continuum 1")
                self.continuum_motor_2_angle = self._update_joint(self.continuum_motor_2_angle + FIVE_DEGREES_FUNCTIONAL, self.MIN_CONTINUUM_ANGLE, self.MAX_CONTINUUM_ANGLE, "Continuum 2")

            case Press.RIGHT_ARROW: 
                self.continuum_motor_3_angle = self._update_joint(self.continuum_motor_3_angle + FIVE_DEGREES_FUNCTIONAL, self.MIN_CONTINUUM_ANGLE, self.MAX_CONTINUUM_ANGLE, "Continuum 3")
                self.continuum_motor_4_angle = self._update_joint(self.continuum_motor_4_angle - FIVE_DEGREES_FUNCTIONAL, self.MIN_CONTINUUM_ANGLE, self.MAX_CONTINUUM_ANGLE, "Continuum 4")
            case Press.LEFT_ARROW: 
                self.continuum_motor_3_angle = self._update_joint(self.continuum_motor_3_angle - FIVE_DEGREES_FUNCTIONAL, self.MIN_CONTINUUM_ANGLE, self.MAX_CONTINUUM_ANGLE, "Continuum 3")
                self.continuum_motor_4_angle = self._update_joint(self.continuum_motor_4_angle + FIVE_DEGREES_FUNCTIONAL, self.MIN_CONTINUUM_ANGLE, self.MAX_CONTINUUM_ANGLE, "Continuum 4")

            case Press.CTRL_C:
                rclpy.shutdown()
                sys.exit(0)

            case _: pass
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

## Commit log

2026-02-26 Added new servo mount sldprt file
    [Servo MG996R.SLDPRT]
2026-02-28 Removed servo SLDPRT part
    [Servo MG996R.SLDPRT]
2026-02-28 Added servo mount top
    [IF_Attachment_Piece_V1.4 Top.STL]
2026-02-28 Added servo mount bottom
    [IF_Attachment_V9_Piece_bottom.STL]
2026-02-28 Added camera link STL
    [IF_camera_frame_V3.0_4.2mm_original.STL]
2026-02-28 Changed file name to work with simulation
    [IF_Attachment_Piece_V1.4_Top.STL]
2026-02-28 Added new servo mount. Added two new links and joints for two new servos
    [rceti_frame_macro.xacro]
2026-02-28 Added license comments and acknowledgements to original authors
    [rceti_frame_macro.xacro]
2026-03-26 Added support for servo 3 and servo 4. Added _update_joint helper method.
2026-03-29 Added support for new servos to communicate with raspberry pi
2026-03-29 Removed all manual keyboard reads. Removed all references to robot head. Added jointStateCallback method to connect to keyboard controller
2026-04-08 Removed kinematic and urdf methods and added documentation
2026-04-08 Holds the Urdf generation code removed from Continuum.cpp
2026-04-08 Added KinematicsEngine and UrdfGenerator to exectuables
2026-04-08 Added min and max angle clamp. Added mock servo generation
2026-04-17 Configure continuum servo ranges.
2026-04-17 Fix servo layout.

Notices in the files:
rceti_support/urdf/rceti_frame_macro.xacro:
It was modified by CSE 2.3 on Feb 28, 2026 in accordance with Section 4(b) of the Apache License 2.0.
